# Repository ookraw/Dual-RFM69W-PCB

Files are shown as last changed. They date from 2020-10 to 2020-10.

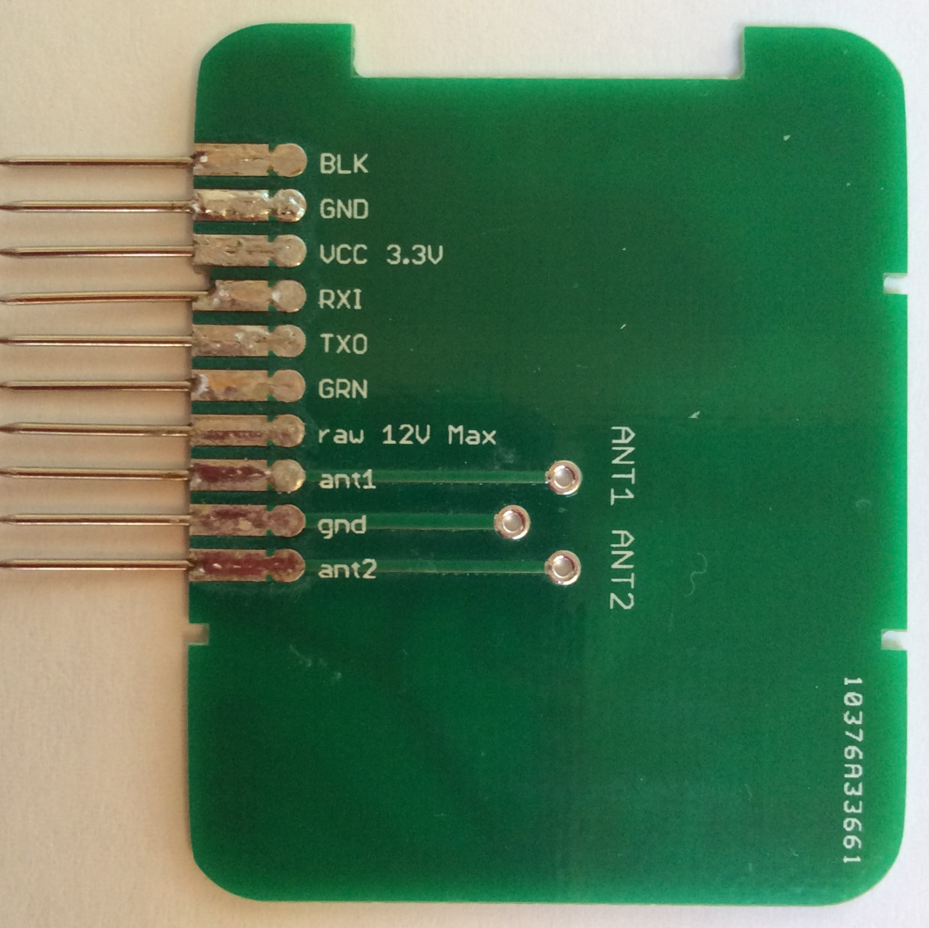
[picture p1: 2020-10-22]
images/PCB3_bot.JPG

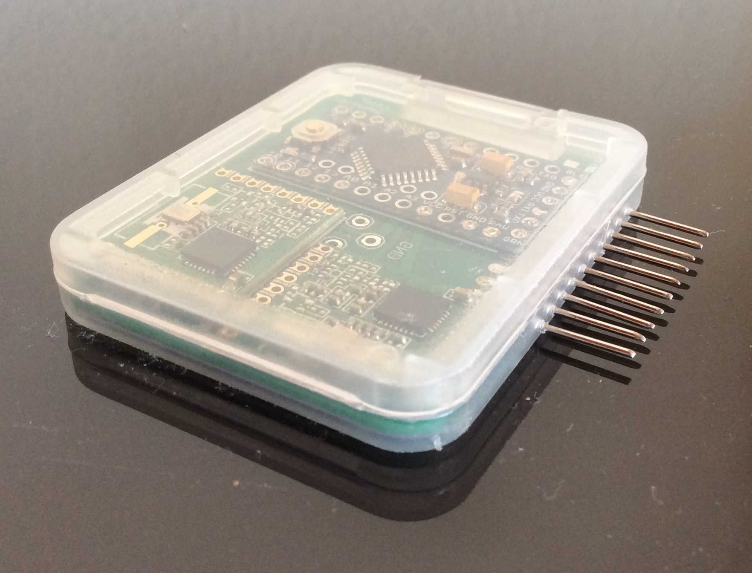
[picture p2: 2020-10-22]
images/PCB4_box.JPG

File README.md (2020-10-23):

Dual RFM69W Transceiver PCB
---------------------------

Designed by Felix Baessler, felix.baessler@gmail.com

The project focuses on the minimization of the costs for connectors and enclosure which quite often even exceed the prize 
you pay for your electronic components. In our daily use, a standard SD card box (ca. 53x43x7 mm) and a couple of steel needles did the job.

### Features:
The HRD_S2.zip file contains all that is required to produce a PCB that fits into a SD card box : <br/> 

- &nbsp;**2 Hope rfm69w radio modules** placed on a common bus
- &nbsp;**1 Arduino compatible mini pro 3.3V (MEGA328P)** microcontroller <br/>
- **10 standard Dupont connectors** fixed in 0.8 mm slots <br/>
  for the attachmant of 2 antennas and a USB-Serial dongle 

### LICENSE
This project is released under [CC-BY-NC 4.0](https://creativecommons.org/licenses/by-nc/4.0/).<br/>
The licensing TLDR is: You are free to use, copy, distribute and transmit this Material for personal, non-commercial purposes, as long as you give attribution and share any modifications under the same license. Commercial or for-profit use requires a license. <br/>
For more details see the [LICENSE](https://github.com/ookraw/Dual-RFM69W-PCB/blob/master/LICENSE)

### Context
The described setup serves as a reference for the [OOK Raw Data Receiver](https://github.com/ookraw/OOK-Raw-Data-Receiver)

### Special Requirement
The enclosed zip-file specifies ten 0.8 mm slots. Make sure that these slots will be edge plated : <br/>
on the top and on the buttom layer and also on the inner side of the slots, like a through hole.

### Project Presentation
An assembled prototype is presented here:  https://sites.google.com/site/rfm69arduino

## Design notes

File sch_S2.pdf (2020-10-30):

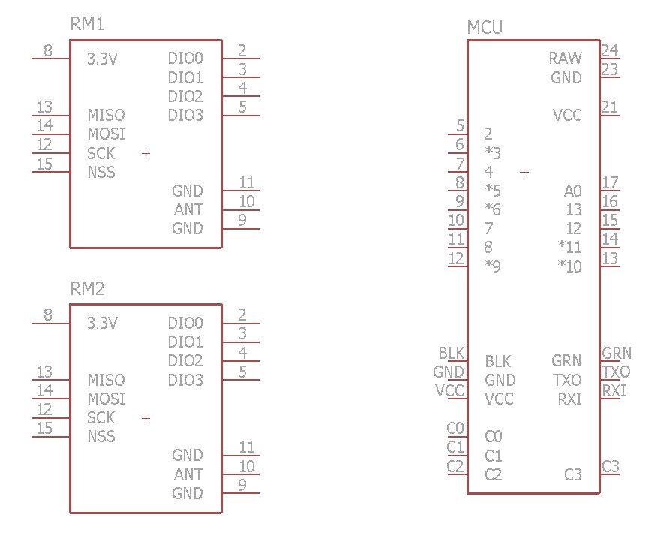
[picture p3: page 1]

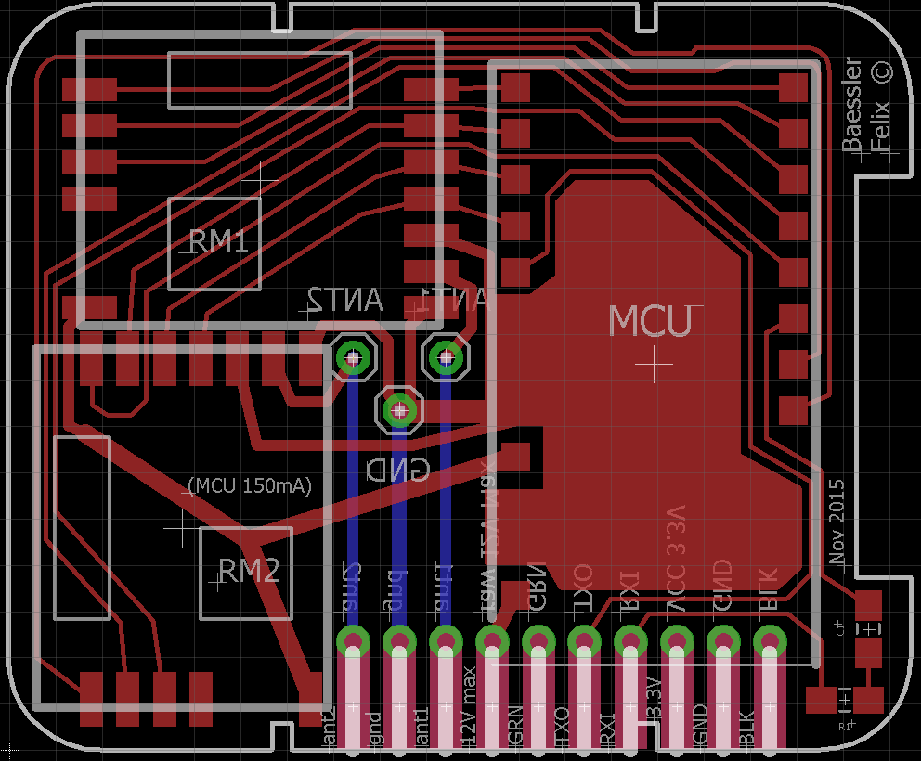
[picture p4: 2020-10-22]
images/PCB1_HRD.png

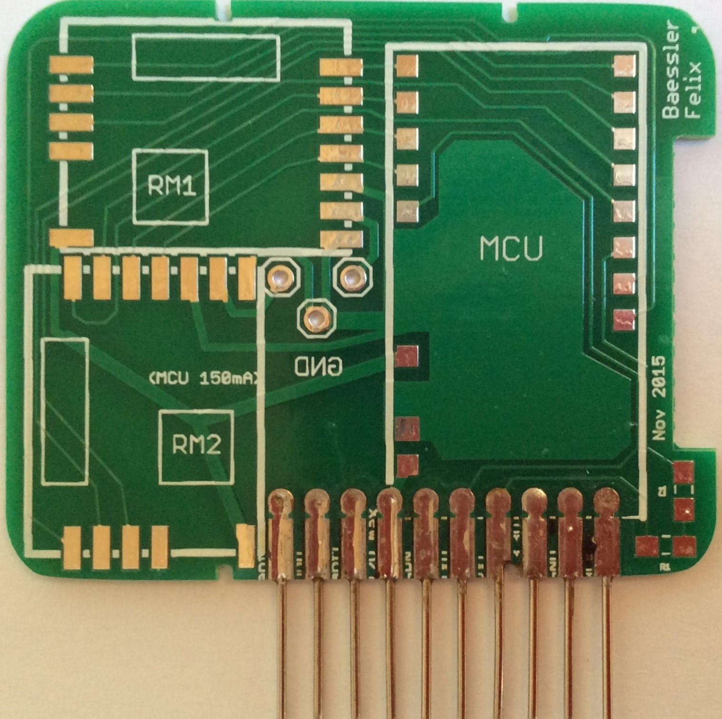
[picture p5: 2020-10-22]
images/PCB2_top.JPG

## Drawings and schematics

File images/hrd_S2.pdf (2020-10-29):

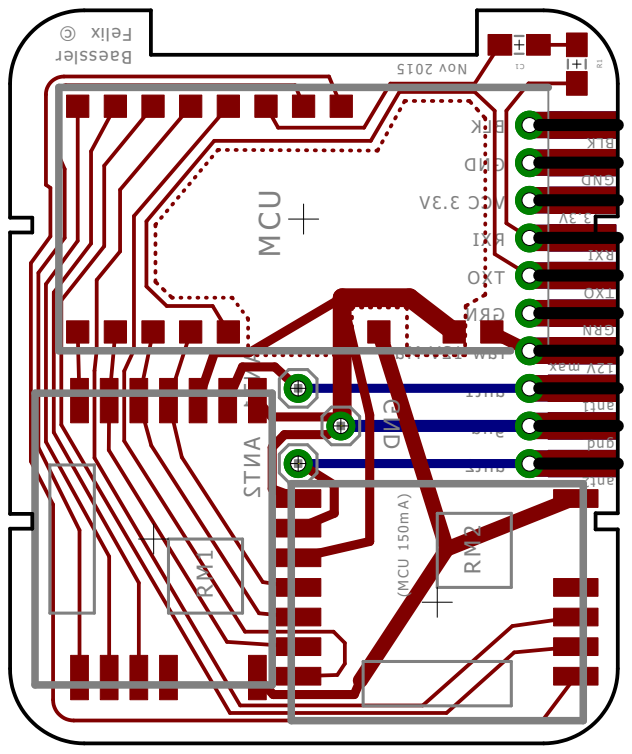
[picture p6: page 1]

ANT2 ANT1 V3. 3 CCV DNG KL B I X R OXT NR G x a M V21 war 1t na dng 2t na r el ss ea B © xil eF 5102 v o N x a m V21 1t na KL B dng DNG NR G 2t na OXT I X R V3. 3 (MCU 150mA) 1 C GND MCU R1 RM1RM2

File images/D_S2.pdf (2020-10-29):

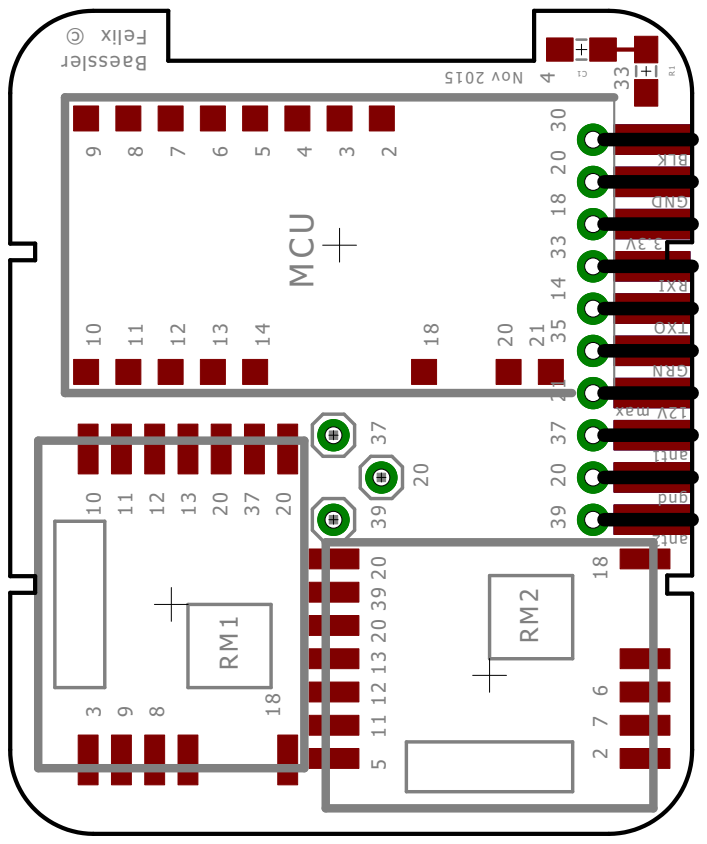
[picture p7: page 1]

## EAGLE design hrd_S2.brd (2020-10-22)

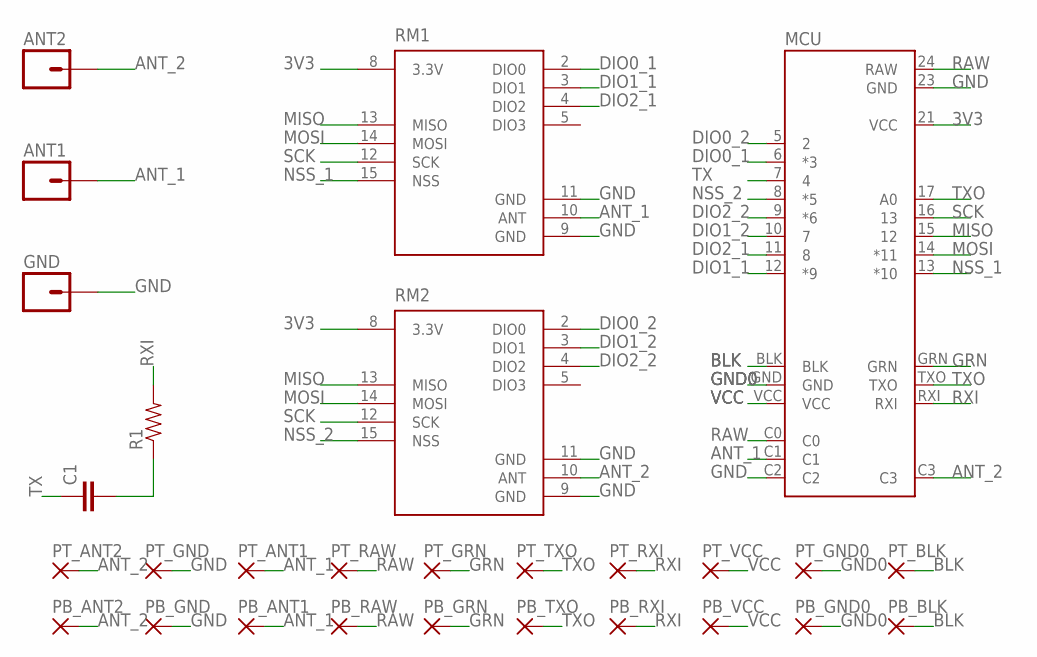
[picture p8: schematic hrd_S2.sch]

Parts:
ANT1, ANT2: M01PTH; 1X01
C1: CAP0805; 0805
GND: M01PTH; 1X01
MCU: APM
PB_ANT1, PB_ANT2: SMD2; SMDSLOT
PB_BLK: SMD2; SMDSLOT
PB_GND, PB_GND0: SMD2; SMDSLOT
PB_GRN: SMD2; SMDSLOT
PB_RAW: SMD2; SMDSLOT
PB_RXI: SMD2; SMDSLOT
PB_TXO: SMD2; SMDSLOT
PB_VCC: SMD2; SMDSLOT
PT_ANT1, PT_ANT2: SMD2; SMDSLOT
PT_BLK: SMD2; SMDSLOT
PT_GND, PT_GND0: SMD2; SMDSLOT
PT_GRN: SMD2; SMDSLOT
PT_RAW: SMD2; SMDSLOT
PT_RXI: SMD2; SMDSLOT
PT_TXO: SMD2; SMDSLOT
PT_VCC: SMD2; SMDSLOT
R1: RESISTOR0805-RES; 0805
RM1, RM2: RFM69HW; RFM69W-XXXS2

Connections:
3V3: MCU.21 (VCC), RM1.8 (3.3V), RM2.8 (3.3V)
ANT_1: ANT1.1, MCU.C1, PB_ANT1.1, PT_ANT1.1, RM1.10 (ANT)
ANT_2: ANT2.1, MCU.C3, PB_ANT2.1, PT_ANT2.1, RM2.10 (ANT)
BLK: MCU.BLK, PB_BLK.1, PT_BLK.1
DIO0_1: MCU.6 (*3), RM1.2 (DIO0)
DIO0_2: MCU.5 (2), RM2.2 (DIO0)
DIO1_1: MCU.12 (*9), RM1.3 (DIO1)
DIO1_2: MCU.10 (7), RM2.3 (DIO1)
DIO2_1: MCU.11 (8), RM1.4 (DIO2)
DIO2_2: MCU.9 (*6), RM2.4 (DIO2)
GND: GND.1, MCU.23 (GND), MCU.C2, PB_GND.1, PT_GND.1, RM1.9 (GND), RM1.11 (GND), RM2.9 (GND), RM2.11 (GND)
GND0: MCU.GND, PB_GND0.1, PT_GND0.1
GRN: MCU.GRN, PB_GRN.1, PT_GRN.1
MISO: MCU.15 (12), RM1.13 (MISO), RM2.13 (MISO)
MOSI: MCU.14 (*11), RM1.14 (MOSI), RM2.14 (MOSI)
unnamed: C1.2, R1.1
NSS_1: MCU.13 (*10), RM1.15 (NSS)
NSS_2: MCU.8 (*5), RM2.15 (NSS)
RAW: MCU.24 (RAW), MCU.C0, PB_RAW.1, PT_RAW.1
RXI: MCU.RXI, PB_RXI.1, PT_RXI.1, R1.2
SCK: MCU.16 (13), RM1.12 (SCK), RM2.12 (SCK)
TX: C1.1, MCU.7 (4)
TXO: MCU.17 (A0), MCU.TXO, PB_TXO.1, PT_TXO.1
VCC: MCU.VCC, PB_VCC.1, PT_VCC.1

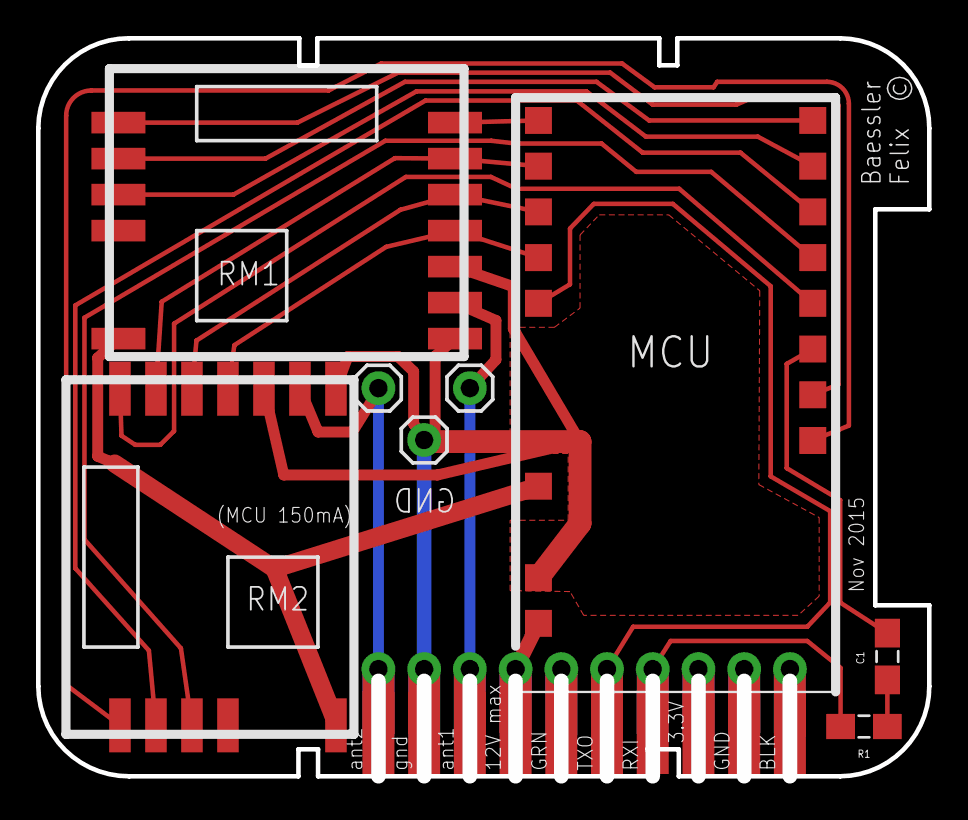
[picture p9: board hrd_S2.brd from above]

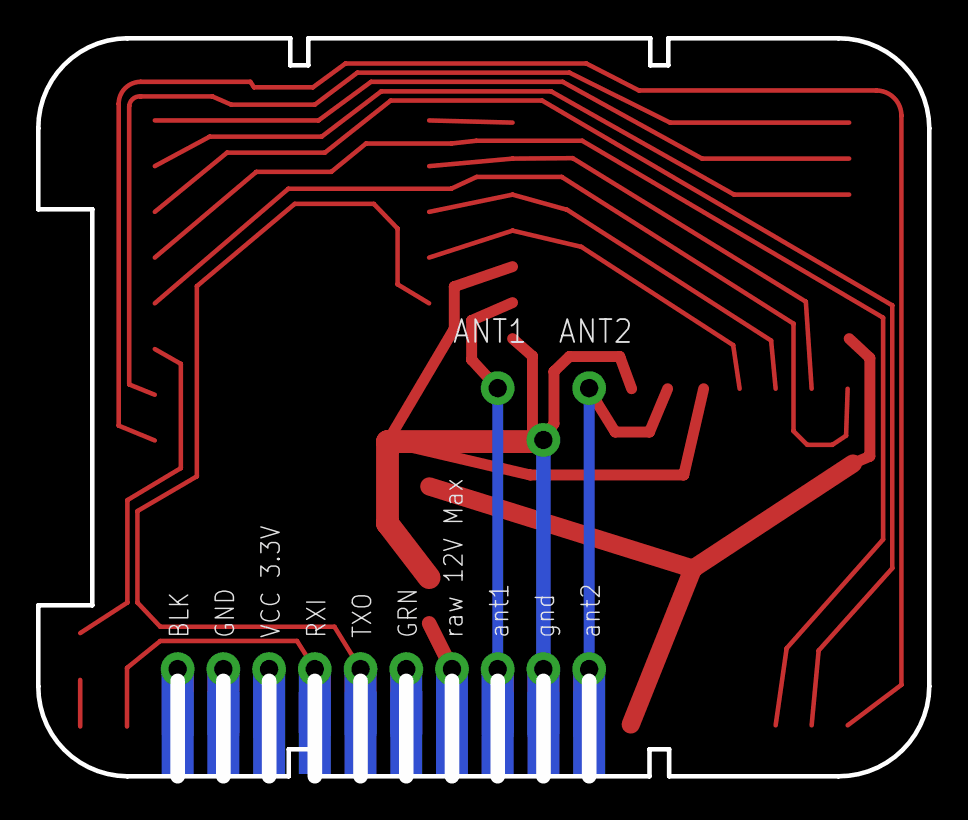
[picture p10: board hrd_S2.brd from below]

Board: 2 copper layers, 49.5 x 41.0 mm, 28 parts (10 on the bottom side), 24 nets.

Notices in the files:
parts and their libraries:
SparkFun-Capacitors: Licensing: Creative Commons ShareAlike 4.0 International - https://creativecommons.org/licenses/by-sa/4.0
